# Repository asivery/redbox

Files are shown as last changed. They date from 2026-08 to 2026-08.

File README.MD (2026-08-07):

# RedBOX

The open-source programmer for Renesas GreenPAK chips with OTP memory.

## Project layout

- `hardware` - contains the schematics and sample PCB design for the programmer
- `software/host` - contains the program which you should run on your PC to communicate with the RedBOX board
- `software/usb` - contains the program which should be written to the RP2040 board

## Compatibility list

**TODO**

Right now no library files are published, as I still need to do more testing before I publish any of them.

## Technical

### Connection with the programmer

The RedBOX programming software communicates with the RedBOX board using a vendor USB interface - make sure you have the appropriate device drivers installed (and access rules set up). 

### The GreenPAK protocol

In the GreenPAK ICs, the OTP is programmed with the help of PCTL and PROG pins. In order to force the GreenPAK into a programming mode, one needs to apply 7.5V to the PROG pin. Even if programmed to disable the built-in I2C interface, after applying that voltage, the GreenPAK should report back, if queried over I2C.

I have observed that before writing the actual program, the Renesas dev board sends a particular sequence, which I decided to call the init sequence, to the chip. I do not know if that is something that needs to be sent to the chip before programming or not, but since the memory is one-time-programmable I decided not to verify that and instead faithfully recreated that initialization sequence's timings in the RP2040 code. Should the need arise, it is possible to define more initialization sequences - the one I mentioned has the ID of `0`. Every GreenPAK description file should define what init sequence the chip uses.

#### Programming the GreenPAK

To program the GreenPAK, one needs to first send the initialization sequence, then bring up power and the 7.5V on `PROG`.
Afterwards, the `PCTL` pin should be set high, and finally the program can be sent over I2C, with the appropriate padding at the front and end of the memory image.

#### Reading data back

To read the program back, one can simply send the first address of the region to be read back, and start reading data over I2C. If the OTP-written program disabled I2C, the data can still be read after sending 7.5V to the `PROG` pin.
**The chip's I2C ID might change in comparison to what it had been before writing OTP!**

It is possible to disable the ability to read the program bytes from the GreenPAK. If this feature is enabled in the image written to the OTP, the program bytes will instead get read back as `0xFF`.

## Credits

- [Pico_WS2812](https://github.com/ForsakenNGS/Pico_WS2812) - Library for controlling the LED on the RP2040 board
- [RP2040-Zero-Kicad](https://github.com/CountParadox/RP2040-Zero-Kicad), [MT3608-module-kicad](https://github.com/barafael/MT3608-module-kicad) - KiCad symbols and footprints for the Waveshare RP2040 Zero board and MT3608 boost converter

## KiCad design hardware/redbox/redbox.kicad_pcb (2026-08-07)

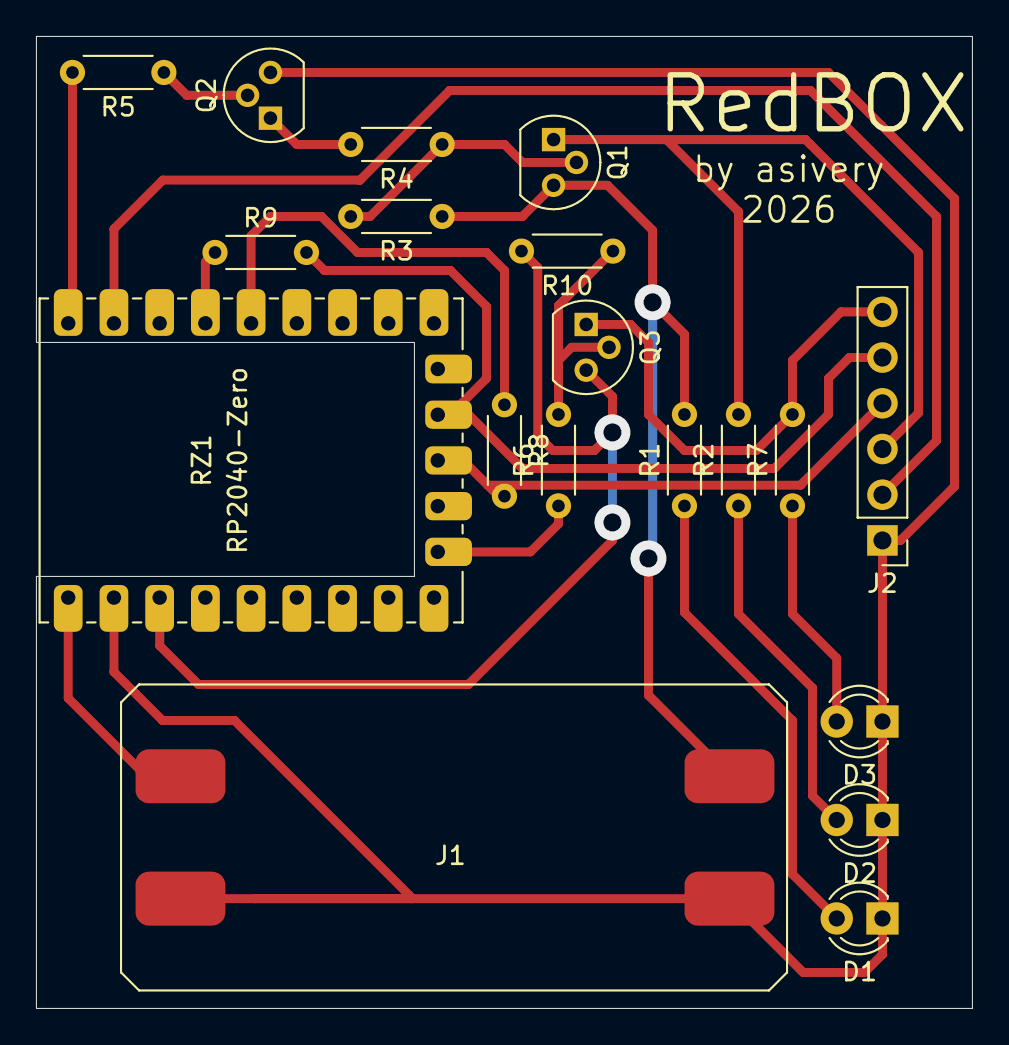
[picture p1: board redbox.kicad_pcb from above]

Board: 2 copper layers, 52.0 x 54.0 mm, 19 parts (0 on the bottom side), 20 nets.

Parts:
D1, D2, D3: LED; LED_D3.0mm
J1: Boost; hw-045
J2: Conn_01x06_Pin; PinHeader_1x06_P2.54mm_Vertical
Q1, Q3: PNP; TO-92
Q2: NPN; TO-92
R1, R2, R3, R4, R5, R6, R7, R8, R9, R10: R; R_Axial_DIN0204_L3.6mm_D1.6mm_P5.08mm_Horizontal
RZ1: RP2040-Zero

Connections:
unnamed: D1.2 (A), R1.1
unnamed: D1.1 (K), D2.1 (K), D3.1 (K), J1.1, J1.4, J2.1, Q2.3 (E), RZ1.22 (GND)
unnamed: D2.2 (A), R2.1
unnamed: D3.2 (A), R7.1
unnamed: J1.2, RZ1.23 (5V)
unnamed: J1.3, Q1.3 (E), R1.2, R3.1
unnamed: J2.2, RZ1.2 (GP1)
unnamed: J2.3, Q1.1 (C), R2.2
unnamed: J2.4, R8.2, RZ1.12 (GP11)
unnamed: J2.5, R9.2, RZ1.11 (GP10)
unnamed: J2.6, Q3.1 (C), R7.2
unnamed: Q1.2 (B), R3.2, R4.1
unnamed: Q2.2 (B), R5.1
unnamed: Q2.1 (C), R4.2
unnamed: Q3.2 (B), R6.2, R10.1
unnamed: Q3.3 (E), R10.2, RZ1.21 (3V3)
unnamed: R5.2, RZ1.1 (GP0)
unnamed: R9.1, RZ1.4 (GP3)
unnamed: R8.1, RZ1.5 (GP4)
unnamed: R6.1, RZ1.14 (GP13)

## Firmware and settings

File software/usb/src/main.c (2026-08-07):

#include <stdio.h>
#include "pico/stdlib.h"
#include "pico/multicore.h"
#include "pico/bootrom.h"
#include "hardware/clocks.h"
#include "hardware/i2c.h"
#include "tusb.h"
#include "bsp/board_api.h"
#include "include.h"
#include "led.h"

#include <stdbool.h>
#include <stddef.h>

#define PIN_HV      0
#define PIN_PGCTRL  1
#define PIN_SDA_PU  4
#define PIN_SCL_PU  5
#define PIN_PWR     13
#define PIN_SDA     10
#define PIN_SCL     11

#define DELAY_PROLOGUE 20
#define DELAY_BLANK 8

#define MAIN_I2C (i2c1)

bool system_configured = false;
bool system_should_program = false;
bool system_should_read = false;
bool system_should_send = false;
bool system_should_read_nopwr = false;
#define I2CPU_MASK (1 << PIN_SDA_PU) | (1 << PIN_SCL_PU)
#define GPIO_ALL_MASK (1 << PIN_HV) | (1 << PIN_PWR) | (1 << PIN_PGCTRL) | I2CPU_MASK

struct  __attribute__((packed)) SystemState {
    uint16_t program_data_length;
    uint16_t checksum;
    uint8_t initseq;
    uint8_t pad;
    uint8_t i2caddrs[0x10];

    uint8_t data[16768];
} payload;

static int errorLine = -1;

static inline void gpio_drive_all(uint32_t mask, uint32_t value) {
    if(value) value = 0xFFFFFFFF;
    gpio_put_masked(mask & ~(1 << PIN_PWR), value);
    // PNP transistor - can't be assed to negate the line in hardware
    gpio_put_masked(mask & (1 << PIN_PWR), ~value);

}
void error_clear_pins() {
    gpio_init_mask(GPIO_ALL_MASK);
    gpio_set_dir_out_masked(GPIO_ALL_MASK);
    gpio_drive_all(GPIO_ALL_MASK, 0);
}

uint8_t locate_i2c_address() {
    uint8_t i2caddr;
    for(int i = 0; i<sizeof(payload.i2caddrs); i++) {
        i2caddr = payload.i2caddrs[i];
        uint8_t data = 0x02;
        if(i2c_write_blocking(MAIN_I2C, i2caddr, &data, 1, false) != PICO_ERROR_GENERIC) {
            return i2caddr;
        }
    }
    return 0xFF;
}

#define CLEAR_ERROR errorLine = 0
#define MARK_ERROR { errorLine = __LINE__; led_red(); }
#define ASSERT_NOT_RV(x, rv) if(x) { printf("Error at %s:%d\n", __FILE__, __LINE__); error_clear_pins(); MARK_ERROR; return rv; }
#define ASSERT_NOT(x) if(x) { printf("Error at %s:%d\n", __FILE__, __LINE__); error_clear_pins(); MARK_ERROR; return; }
#define CHECKING_ERROR_GENERIC(x) ASSERT_NOT ((x) == PICO_ERROR_GENERIC)

void send_init_prologue_zero() {
    // Zero
    sleep_ms(60);
    led_blue();
    gpio_drive_all(GPIO_ALL_MASK, 0);
    sleep_ms(60);

    // Part 1:
    gpio_drive_all(I2CPU_MASK | (1 << PIN_PWR), 1);
    sleep_ms(11);
    gpio_put(PIN_HV, 1);
    sleep_ms(5);
    gpio_drive_all(GPIO_ALL_MASK, 0);
    sleep_ms(60);

    // Part 2:
    gpio_drive_all(I2CPU_MASK | (1 << PIN_PWR) | (1 << PIN_PGCTRL), 1);
    sleep_ms(11);
    gpio_put(PIN_HV, 1);
    sleep_ms(5);
    gpio_drive_all(GPIO_ALL_MASK, 0);
    sleep_ms(60);
    // Part 3:
    gpio_drive_all(I2CPU_MASK | (1 << PIN_PWR) | (1 << PIN_PGCTRL), 1);
    sleep_ms(11);
    gpio_put(PIN_HV, 1);
    sleep_ms(4);
    gpio_put(PIN_PGCTRL, 1);
    sleep_ms(3);
    gpio_drive_all(GPIO_ALL_MASK, 0);
    sleep_ms(60);
    // Part 4:
    gpio_drive_all(1 << PIN_SDA_PU | (1 << PIN_PWR), 1);
    sleep_ms(11);
    gpio_put(PIN_HV, 1);
    sleep_ms(5);
    gpio_drive_all(GPIO_ALL_MASK, 0);
    sleep_ms(60);
    // Part 3 again:
    gpio_drive_all(I2CPU_MASK | (1 << PIN_PGCTRL) | (1 << PIN_PWR), 1);
    sleep_ms(11);
    gpio_put(PIN_HV, 1);
    sleep_ms(4);
    gpio_put(PIN_PGCTRL, 1);
    sleep_ms(3);
    gpio_drive_all(GPIO_ALL_MASK, 0);
    sleep_ms(60);
    // Part 2 (again):
    gpio_drive_all(I2CPU_MASK | (1 << PIN_PGCTRL) | (1 << PIN_PWR), 1);
    sleep_ms(11);
    gpio_put(PIN_HV, 1);
    sleep_ms(5);
    gpio_drive_all(GPIO_ALL_MASK, 0);
    sleep_ms(60);
}

#define MAX_INITSEQ 0
void send_init_prologue() {
    switch(payload.initseq){
        case 0:
            send_init_prologue_zero();
            break;
    }
}

void perform_read() {
    system_should_read = 0;
    gpio_drive_all(GPIO_ALL_MASK, 0);
    led_blue();
    sleep_ms(32);

    send_init_prologue();

    gpio_drive_all(I2CPU_MASK | (1 << PIN_PWR), 1);
    sleep_ms(32);
    gpio_put(PIN_HV, 1);
    led_yellow();
    sleep_ms(32);

    i2c_init(MAIN_I2C, 20*1000);
    uint8_t addr = locate_i2c_address();
    ASSERT_NOT(addr == 0xFF);

    uint8_t start_reg = 0;
    CHECKING_ERROR_GENERIC(i2c_write_blocking(MAIN_I2C, addr, &start_reg, sizeof(start_reg), true));

    int size_to_read = payload.program_data_length;
    if(size_to_read == 0) size_to_read = sizeof(payload.data);
    CHECKING_ERROR_GENERIC(
        payload.program_data_length = i2c_read_blocking(MAIN_I2C, addr, payload.data, size_to_read, false)
    );

    gpio_drive_all(GPIO_ALL_MASK, 0);
    memset(payload.i2caddrs, addr, sizeof(payload.i2caddrs));
    payload.checksum = 0;
    for(int i = 0; i<sizeof(payload.data); i++) payload.checksum += payload.data[i];
    payload.checksum &= ~1;
    printf("Read back %d bytes from the chip. Address is %x. Checksum is %x\n", payload.program_data_length, payload.i2caddrs[0], payload.checksum);
    led_green();
    CLEAR_ERROR;
}

void perform_simple_send() {
    system_should_send = false;
    // Zero is still valid for reads.
    ASSERT_NOT(payload.program_data_length == 0);

    gpio_drive_all(GPIO_ALL_MASK, 0);
    led_blue();
    sleep_ms(20);
    led_yellow();

    sleep_ms(10);
    // 1st bit of checksum = should engage programming pin.
    gpio_drive_all(I2CPU_MASK | (1 << PIN_PWR), 1);

    sleep_ms(4);
    i2c_init(MAIN_I2C, 20*1000);
    sleep_ms(32);


    sleep_ms(32);

    uint8_t addr = locate_i2c_address();
    ASSERT_NOT(addr == 0xFF);

    sleep_ms(12);

    i2c_write_blocking(MAIN_I2C, addr, payload.data, payload.program_data_length, false);

    sleep_ms(32);

    // Leave the power enabled.
    led_green();
    CLEAR_ERROR;
}

void perform_simple_read() {
    system_should_read_nopwr = false;

    sleep_ms(20);
    led_yellow();

    sleep_ms(10);
    // 1st bit of checksum = should engage programming pin.
    gpio_drive_all(I2CPU_MASK | (1 << PIN_PWR), 1);

    sleep_ms(4);
    i2c_init(MAIN_I2C, 20*1000);
    sleep_ms(32);


    sleep_ms(32);

    uint8_t addr = locate_i2c_address();
    ASSERT_NOT(addr == 0xFF);

    sleep_ms(12);

    i2c_write_blocking(MAIN_I2C, addr, payload.data, payload.program_data_length, false);

    sleep_ms(32);

    uint8_t start_reg = 0;
    CHECKING_ERROR_GENERIC(i2c_write_blocking(MAIN_I2C, addr, &start_reg, sizeof(start_reg), true));

    int size_to_read = payload.program_data_length;
    if(size_to_read == 0) size_to_read = sizeof(payload.data);
    CHECKING_ERROR_GENERIC(
        payload.program_data_length = i2c_read_blocking(MAIN_I2C, addr, payload.data, size_to_read, false)
    );

    gpio_drive_all(GPIO_ALL_MASK, 0);
    memset(payload.i2caddrs, addr, sizeof(payload.i2caddrs));
    payload.checksum = 0;
    for(int i = 0; i<sizeof(payload.data); i++) payload.checksum += payload.data[i];
    payload.checksum &= ~1;
    printf("Read back %d bytes from the chip (without reset). Address is %x. Checksum is %x\n", payload.program_data_length, payload.i2caddrs[0], payload.checksum);
    led_green();
    CLEAR_ERROR;
}

void perform_program() {
    system_should_program = false;
    // Zero is still valid for reads.
    ASSERT_NOT(payload.program_data_length == 0);

    gpio_drive_all(GPIO_ALL_MASK, 0);
    led_blue();
    sleep_ms(20);

    send_init_prologue();

    led_yellow();

    sleep_ms(10);
    // 1st bit of checksum = should engage programming pin.
    gpio_put(PIN_PGCTRL, payload.checksum & 1);
    gpio_drive_all(I2CPU_MASK | (1 << PIN_PWR), 1);

    sleep_ms(4);
    i2c_init(MAIN_I2C, 20*1000);
    sleep_ms(32);


    gpio_put(PIN_HV, 1);
    sleep_ms(32);

    uint8_t addr = locate_i2c_address();
    ASSERT_NOT(addr == 0xFF);

    sleep_ms(12);

    i2c_write_blocking(MAIN_I2C, addr, payload.data, payload.program_data_length, false);
    
    sleep_ms(32);

    gpio_put(PIN_HV, 0);
    sleep_ms(32);

    gpio_drive_all(GPIO_ALL_MASK, 0);

    led_green();
    CLEAR_ERROR;
}

void main(void) {
    uint32_t i2cmask = (1 << PIN_SCL) | (1 << PIN_SDA);
    set_sys_clock_khz(240000, 1);
    board_init();
    tusb_init();
    board_init_after_tusb();
    led_init();
    led_magenta();
    stdio_init_all();
    gpio_set_function_masked(i2cmask, GPIO_FUNC_I2C);

    gpio_init_mask(GPIO_ALL_MASK);
    gpio_set_dir_out_masked(GPIO_ALL_MASK);
    gpio_drive_all(GPIO_ALL_MASK, 0);

    sleep_ms(10);



    while (true) {
        tud_task();
        led_tick();

        if(system_should_program) {
            perform_program();
        }
        if(system_should_read) {
            perform_read();
        }
        if(system_should_send){
            perform_simple_send();
        }
        if(system_should_read_nopwr){
            perform_simple_read();
        }
    }
}

// Vendor code:

uint32_t bulk_write_offset = 0;
uint32_t bulk_read_offset = 0;

void tud_vendor_rx_cb(uint8_t itf, uint8_t const* buffer, uint16_t bufsize) {
    if(itf == ITF_NUM_VENDOR) {
        if((bulk_write_offset + bufsize) > sizeof(payload)) {
            MARK_ERROR;
            printf("Too much data!\n");
        } else {
            memcpy(((uint8_t *) &payload) + bulk_write_offset, buffer, bufsize);
            printf("Payload[%x..%x] written.\n", bulk_write_offset, bulk_write_offset + bufsize);
            bulk_write_offset += bufsize;
        }
    }
#if CFG_TUD_VENDOR_RX_BUFSIZE > 0
    tud_vendor_read_flush();
#endif
    return;
}

void tud_vendor_tx_cb(uint8_t itf, uint32_t sent_bytes) {
    bulk_read_offset += sent_bytes;
    int bytes_remaining = offsetof(struct SystemState, data) + payload.program_data_length - bulk_read_offset;
    if(bytes_remaining > 64) bytes_remaining = 64;
    if(bytes_remaining > 0) {
        tud_vendor_write(((uint8_t *)&payload) + bulk_read_offset, bytes_remaining);
    }
}


bool tud_vendor_control_xfer_cb(uint8_t rhport, uint8_t stage, tusb_control_request_t const* request) {
    union {
        uint8_t rawByte;
        uint32_t errorLine;
        uint32_t length;
    } usbData;
    static uint8_t responseLength;

    // Used to test the direction
    bool isInbound = (request->bmRequestType_bit.direction == TUSB_DIR_IN) ? true : false; 

    if (request->bmRequestType_bit.type != TUSB_REQ_TYPE_CLASS || request->wIndex != ITF_NUM_VENDOR) {
        return false;
    }

    switch (stage) {
        case CONTROL_STAGE_SETUP:
            memset(&usbData, 0, sizeof(usbData));

            // Handle the request
            switch (request->bRequest) {
                case 1:
                    // OUT: Program - trigger the flashing of the GP. - out
                    if (isInbound) {
                        MARK_ERROR;
                        return false;
                    }

                    if (!system_configured) {
                        MARK_ERROR;
                    } else {
                        system_should_program = true;
                        errorLine = -1;
                    }

                    responseLength = 1;
                    break;
                case 2:
                    // OUT: Reset
                    if (isInbound) {
                        MARK_ERROR;
                        return false;
                    }
                    bulk_write_offset = 0;
                    errorLine = -1;
                    break;
                case 3:
                    // OUT: Validate and reset
                    {
                        if (isInbound) {
                            return false;
                        }

                        ASSERT_NOT_RV(payload.initseq > MAX_INITSEQ, false);

                        uint16_t sum = 0;
                        memset(payload.data + payload.program_data_length, 0, sizeof(payload.data) - payload.program_data_length);
                        for(int i = 0; i<sizeof(payload.data); i++)
                            sum += payload.data[i];
                        sum &= ~1;
                        if(sum != (payload.checksum & ~1)) {
                            printf("Checksum err: %x != %x\n", sum, payload.checksum & ~1);
                            MARK_ERROR;
                        } else {
                            printf("Checksum OK. System primed\n");
                            system_configured = true;
                            CLEAR_ERROR;
                        }
                        bulk_write_offset = 0;
                    }
                    break;
                case 4:
                    // OUT: Trigger read
                    if(isInbound) {
                        MARK_ERROR;
                        return false;
                    }

                    if (!system_configured) {
                        MARK_ERROR;
                    } else {
                        system_should_read = true;
                        errorLine = -1;
                    }
                    break;
                case 5:
                    // OUT: Just write the data over i2c
                    if (isInbound) {
                        MARK_ERROR;
                        return false;
                    }

                    if (!system_configured) {
                        MARK_ERROR;
                    } else {
                        system_should_send = true;
                        errorLine = -1;
                    }

                    responseLength = 1;
                    break;
                case 6:
                    // OUT: Read data from I2c without resetting
                    if (isInbound) {
                        MARK_ERROR;
                        return false;
                    }

                    if (!system_configured) {
                        MARK_ERROR;
                    } else {
                        system_should_read_nopwr = true;
                        errorLine = -1;
                    }

                    responseLength = 1;
                    break;
                case 0xFC:
                    // IN: Read header
                    if(!isInbound) return false;
                    usbData.length = offsetof(struct SystemState, data) + payload.program_data_length;
                    responseLength = sizeof(usbData.length);
                    break;
                case 0xFD:
                    // In: Read program data
                    if(!isInbound) return false;
                    responseLength = 1;
                    bulk_read_offset = 0;
                    tud_vendor_write(&payload, CFG_TUD_CDC_TX_BUFSIZE);
                    break;
                case 0xFE:
                    // IN: Read error
                    if(!isInbound) return false;
                    responseLength = sizeof(errorLine);
                    usbData.errorLine = (uint32_t) errorLine;
                    break;
                default:
                    return false;
            }

            return tud_control_xfer(rhport, request, &usbData, responseLength);
        case CONTROL_STAGE_DATA:
            // The buffer is filled - from PC to dev.

        default:
            return true;
    }
}

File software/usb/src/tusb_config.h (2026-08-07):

//
// Copyright (c) 2025 Piers Finlayson <piers@piers.rocks>
//
// Licensed under MIT license - see https://opensource.org/licenses/MIT
//

//
// This is the configuration file for the tinyusb stack for the tinyusb
// vendor example.
//
// This configuration file (or one like it) is required to implement any
// USB host or device using tinyusb, and is included by tinyusb to configure
// the features of the stack.
//

#ifndef TUSB_CONFIG_H
#define TUSB_CONFIG_H

#ifdef __cplusplus
extern "C" {
#endif

//--------------------------------------------------------------------
// COMMON CONFIGURATION
//--------------------------------------------------------------------

// Define to use FLASH helper for persistent storage
// #define CFG_TUD_FLASH_XFER_BUFFER   1

// Defined by compiler flags for flexibility
#ifndef CFG_TUSB_MCU
#error CFG_TUSB_MCU must be defined
#endif

// RHPort number used for device can be defined by board.mk, default to port 0
#ifndef BOARD_TUD_RHPORT
#define BOARD_TUD_RHPORT     0
#endif

// RHPort max operational speed can be defined by board.mk
// Default to Highspeed for MCU with internal HighSpeed PHY (can be port specific), otherwise FullSpeed
#ifndef BOARD_TUD_MAX_SPEED
#define BOARD_TUD_MAX_SPEED  OPT_MODE_FULL_SPEED
#endif

// Default is max speed that hardware controller could support with on-chip PHY
#define CFG_TUD_MAX_SPEED    BOARD_TUD_MAX_SPEED

// Device mode with rhport and speed defined by board.mk
#define CFG_TUSB_RHPORT0_MODE   (OPT_MODE_DEVICE | BOARD_TUD_MAX_SPEED)

#ifndef CFG_TUSB_OS
#define CFG_TUSB_OS           OPT_OS_NONE
#endif

// CFG_TUSB_DEBUG is defined by compiler in DEBUG build
#ifdef CFG_TUSB_DEBUG
#undef CFG_TUSB_DEBUG
#endif
#define CFG_TUSB_DEBUG 0  // Increase number to enable tinyusb logging

// Enable device support
#define CFG_TUD_ENABLED       1

//--------------------------------------------------------------------
// DEVICE CONFIGURATION
//--------------------------------------------------------------------

#define CFG_TUD_ENDPOINT0_SIZE    64

//------------- CLASS -------------//

// Vendor specific class configuration
#define CFG_TUD_VENDOR           1
#define CFG_TUD_VENDOR_EP_BUFSIZE  64
#define CFG_TUD_VENDOR_RX_BUFSIZE  64
#define CFG_TUD_VENDOR_TX_BUFSIZE  64
#define CFG_TUD_VENDOR_TX_BUFSIZE  64
#define CFG_TUD_HID_EP_BUFSIZE

    #define CFG_TUD_CDC_TX_BUFSIZE  64
    #define CFG_TUD_CDC_RX_BUFSIZE  64

// DFU RT does not required for this project
#define CFG_TUD_DFU_RT           0

// CDC class is not needed
#define CFG_TUD_CDC              1

// MSC class is not needed
#define CFG_TUD_MSC              0

// One HID device
#define CFG_TUD_HID              0

// MIDI class is not needed
#define CFG_TUD_MIDI             0

// Audio class is not needed
#define CFG_TUD_AUDIO            0

// Video class is not needed
#define CFG_TUD_VIDEO            0

// BTH class is not needed
#define CFG_TUD_BTH              0

#ifdef __cplusplus
}
#endif

#endif // TUSB_CONFIG_H

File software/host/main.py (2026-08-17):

from redbox import RedBox, SystemData, pack_nvm_format_to_binary
from argparse import ArgumentParser
from dataclasses import dataclass, field
import tomllib
import os

@dataclass
class ChipWriteData:
    engagepctl: bool = False
    padstart: bytes = b''
    padend: bytes = b''
    # [[bitreg, value], [bitreg2, value2]]
    forceadjust: list[list[int]] = field(default_factory=list)

    def apply_forceadjust(self, image: bytes) -> bytes:
        image = list(image)
        for (register_bit_no, value) in self.forceadjust:
            base, bit_off = divmod(register_bit_no, 8)
            if value:
                image[base] |= (1 << bit_off)
            else:
                image[base] &= ~(1 << bit_off)
        return bytes(image)


    def prepare_image(self, image: bytes, ignore_forceadjust: bool):
        if not ignore_forceadjust:
            image = self.apply_forceadjust(image)
        return self.padstart + image + self.padend

@dataclass
class Lockout:
    name: str
    description: str
    # Raw:
    # [[addr, 'OP', value], ...] where addr is value from OTP image, OP in ['AND', 'OR', 'XOR'], value is byte.
    raw: list = None
    reflect: list[str] = None

@dataclass
class ChipData:
    chip: str # Name
    i2caddrs: list[int] # The list of i2c addresses to try out.
    initseq: int # ID of the init sequence
    programsize: int
    verification_mask: bytes

    write_ram_data: ChipWriteData = field(default_factory=ChipWriteData) # Config for writing RAM
    write_otp_data: ChipWriteData = field(default_factory=ChipWriteData) # Config for writing OTP

    lockout_instructions: list[Lockout] = field(default_factory=list)

    def build_system_data_for_otp(self, content: bytes, ignore_forceadjust: bool):
        return SystemData(self.i2caddrs, self.write_otp_data.engagepctl, self.write_otp_data.prepare_image(content, ignore_forceadjust), self.initseq)

    def build_system_data_for_ram(self, content: bytes, ignore_forceadjust: bool):
        return SystemData(self.i2caddrs, self.write_ram_data.engagepctl, self.write_ram_data.prepare_image(content, ignore_forceadjust), self.initseq)

    def mask_data_for_verification(self, data: bytes) -> bytes:
        return bytes(a & b for a, b in zip(data, self.verification_mask))

def read_image(name: str) -> bytes:
    with open(name, 'rb') as e:
        raw = e.read()
    if name.lower().endswith('.txt'):
        raw = pack_nvm_format_to_binary(raw.decode('ascii'))
    return raw

def parse_chip_write_data(from_file: dict[str, any]) -> ChipWriteData:
    out = ChipWriteData()
    out.engagepctl = from_file.get('engagepctl', False)
    out.padstart = bytes(from_file.get('padstart', []))
    out.padend = bytes(from_file.get('padend', []))
    out.forceadjust = from_file.get('forceadjust', [])
    return out

def form_system_data_from_library(chip_name: str) -> ChipData:
    path = chip_name if chip_name.endswith('.toml') else os.path.join(os.path.split(__file__)[0], 'library', chip_name + '.toml')
    with open(path, 'rb') as fd:
        content = tomllib.load(fd)
    chip_data = ChipData(content['meta']['chip'], content['meta']['i2caddrs'], content['meta']['initseq'], content['meta']['programsize'], bytes.fromhex(content['meta']['verification_mask']))
    if 'write_ram' in content:
        chip_data.write_ram_data = parse_chip_write_data(content['write_ram'])
    if 'write_otp' in content:
        chip_data.write_otp_data = parse_chip_write_data(content['write_otp'])
    if len(chip_data.verification_mask) != chip_data.programsize:
        raise BaseException("Invalid library file: Verification mask length does not match program data length")

    if 'lockout' in content:
        if not isinstance(content['lockout'], list):
            raise BaseException("Invalid library file: Lockout is not a list of possible lockout modes")
        lockouts = []
        lockout_exist = lambda e: sum(1 for x in lockouts if x.name == e) > 0
        for x in content['lockout']:
            entry = Lockout(x['name'], x['description'])
            if 'reflect' in x:
                # Check if all reflect paths exist
                reflect_paths = x['reflect'].split('+')
                if not all(lockout_exist(x) for x in reflect_paths):
                    raise BaseException(f"Invalid reflect path for lockout mode {entry.name}")
                entry.reflect = reflect_paths
            if 'raw' in x:
                steps = x['raw']
                if not isinstance(steps, list):
                    raise BaseException("Invalid library file: Lockout's raw attribute is not a list of steps")
                for i, x in enumerate(steps):
                    if  not isinstance(x, list) or \
                        x[0] >= chip_data.programsize or \
                        x[1] not in ['OR', 'AND', 'XOR', 'SET'] or \
                        x[2] not in range(0, 256) or \
                        not isinstance(x[0], int) or \
                        not isinstance(x[2], int):
                            raise BaseException(f"Invalid library file: Invalid step {i}")
                entry.raw = steps
            if not (bool(entry.raw) ^ bool(entry.reflect)):
                raise BaseException("Invalid library file. Lockout must be either 'raw' or 'reflect'!")
            lockouts.append(entry)
        chip_data.lockout = lockouts


    return chip_data


def write_ram(args):
    rb = RedBox()
    contents = read_image(args.file)
    chip_data = form_system_data_from_library(args.chip)
    if len(contents) != chip_data.programsize:
        print("Program size doesn't match the definition in library file!'")
        return;
    rb.write_system_data(chip_data.build_system_data_for_ram(contents, args.ignore_forceadjust))
    rb.write_ram()
    print("OK")
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
